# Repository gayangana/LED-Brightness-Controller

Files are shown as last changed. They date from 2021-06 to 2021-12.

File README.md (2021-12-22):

# LED-Brightness-Controller
LED brightness controller with constant current LED drivers

<p align="center">
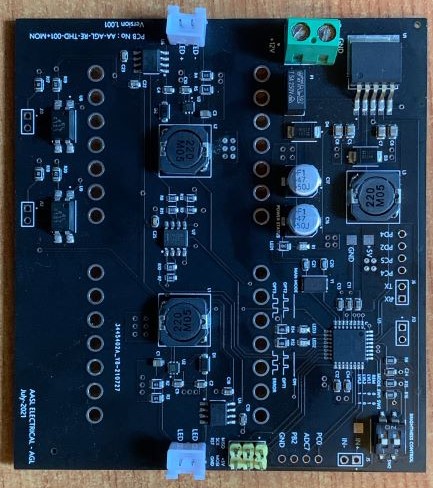
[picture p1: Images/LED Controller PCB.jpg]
  
<p>
  
## Features
- Operates at 12V singal supply
- 2 Ouput channels
- Minimum output voltage - 5V
- Maximum output voltage - 35V
- Maximum output current per channel - 350mA
- LED brightness control with 256 steps (8 bit PWM)
- Overcurrent protection - Maximum input current (5A)
- Current sense capability
- General purpose input/ outputs

## Top Level Block Diagram

<p align="left">
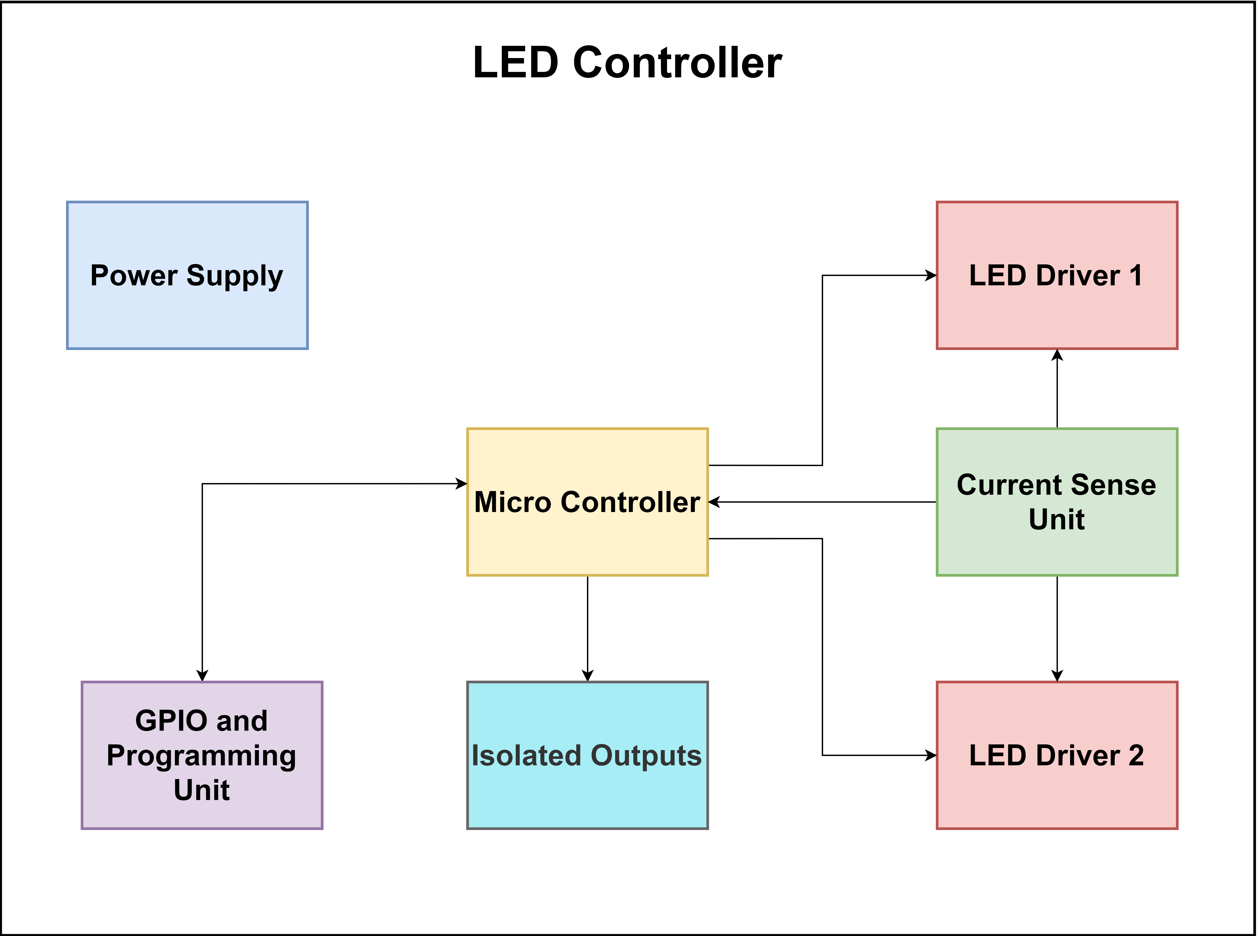
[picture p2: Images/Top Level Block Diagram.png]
  
<p>

## Power Supply Unit - Block Diagram

<p align="left"> 
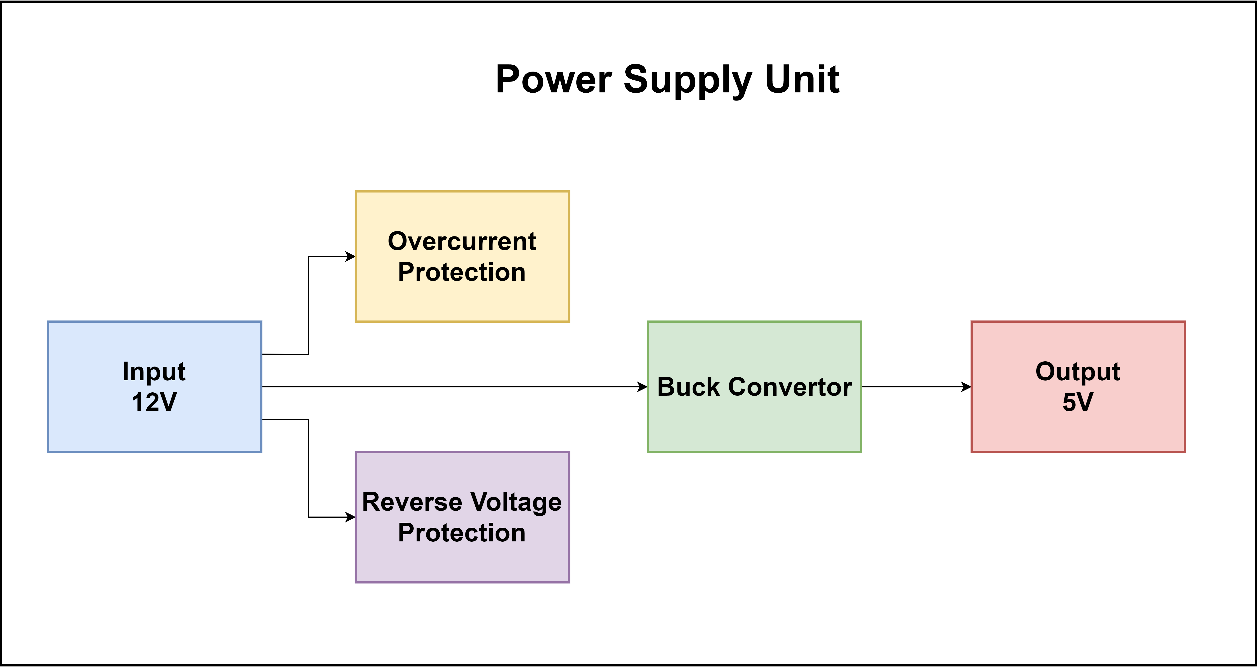
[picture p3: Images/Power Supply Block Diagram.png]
  
<p>

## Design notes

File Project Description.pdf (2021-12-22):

## Primary Objectives

# Design a LED Controller Board

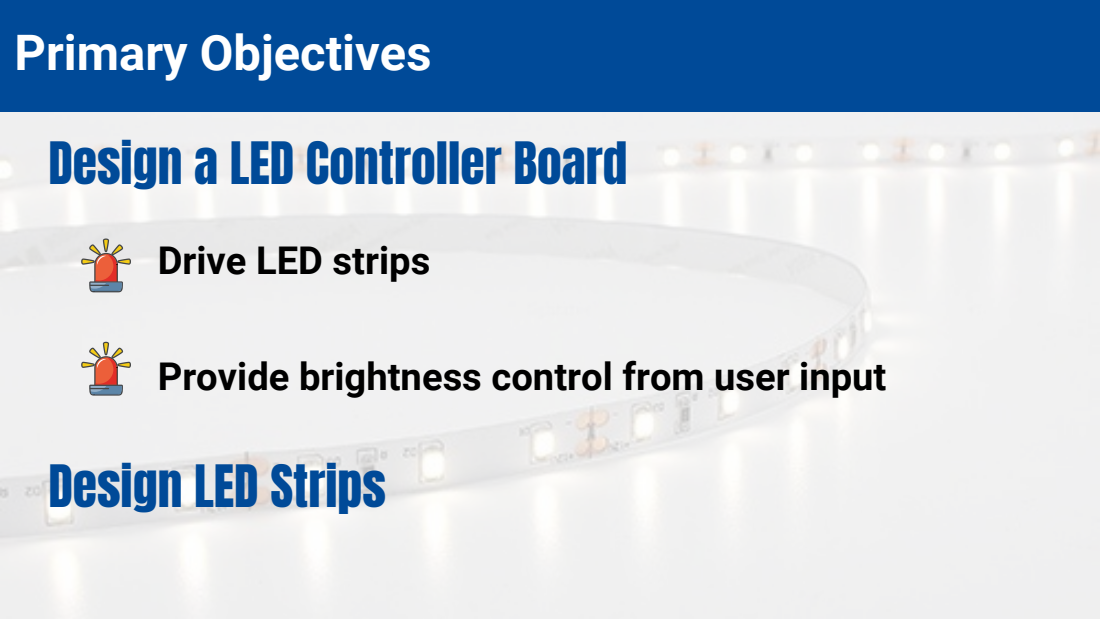
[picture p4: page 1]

Drive LED strips

Provide brightness control from user input
Design LED Strips

## Block Diagram of LED Controller

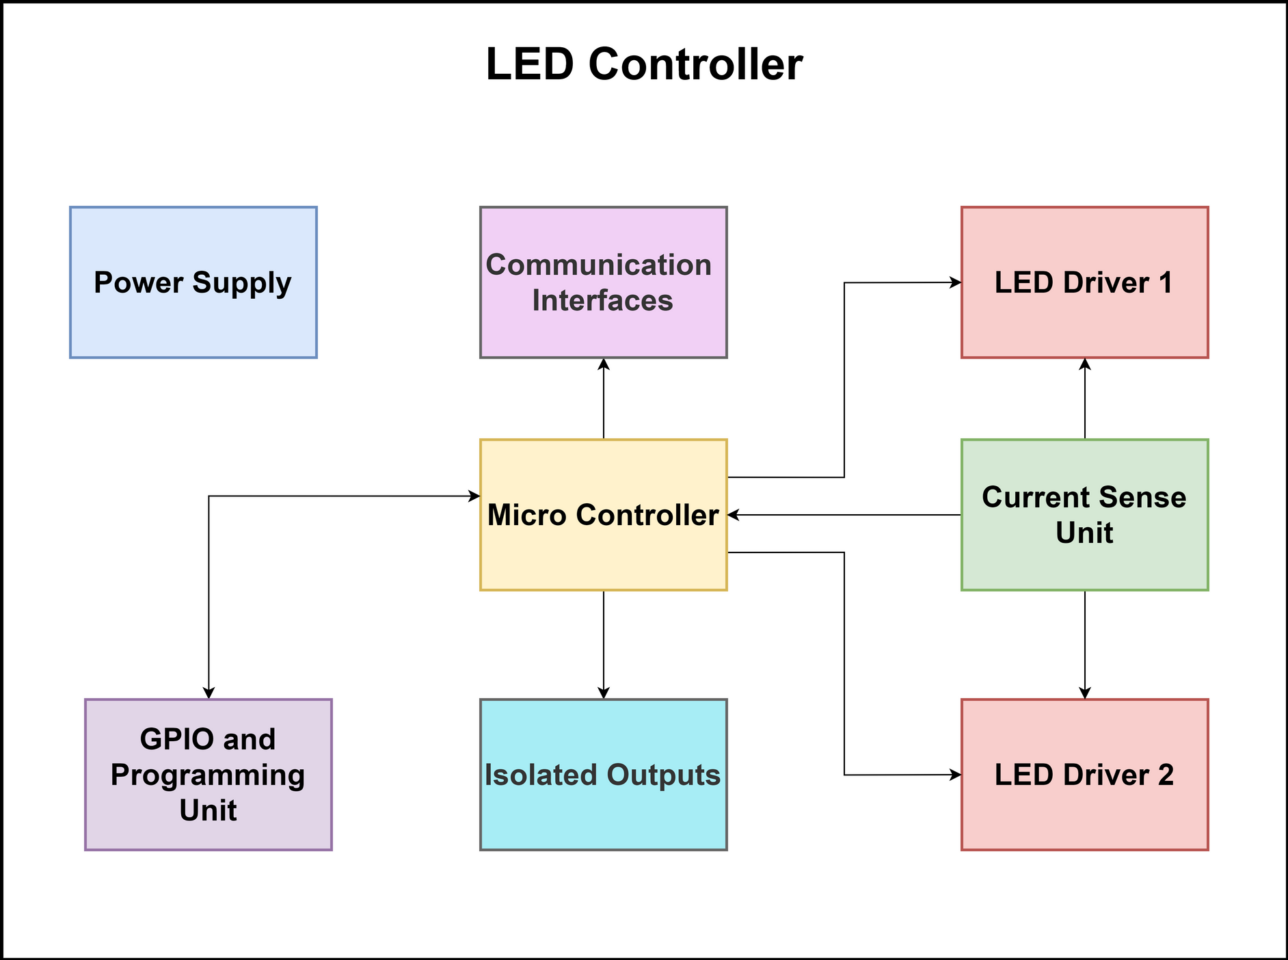
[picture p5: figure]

## Power Supply Unit - Schematic

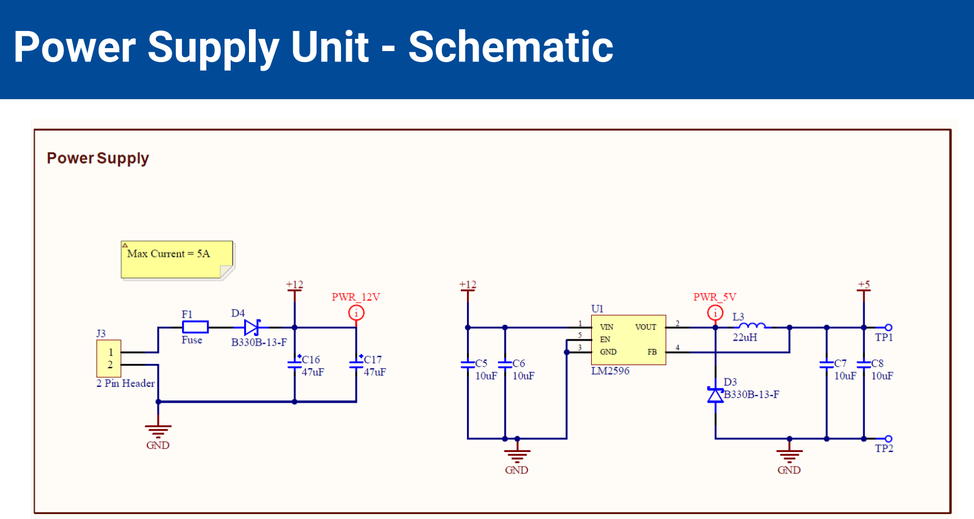
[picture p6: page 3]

## LED Driver

## LED Driver IC : TPS6115

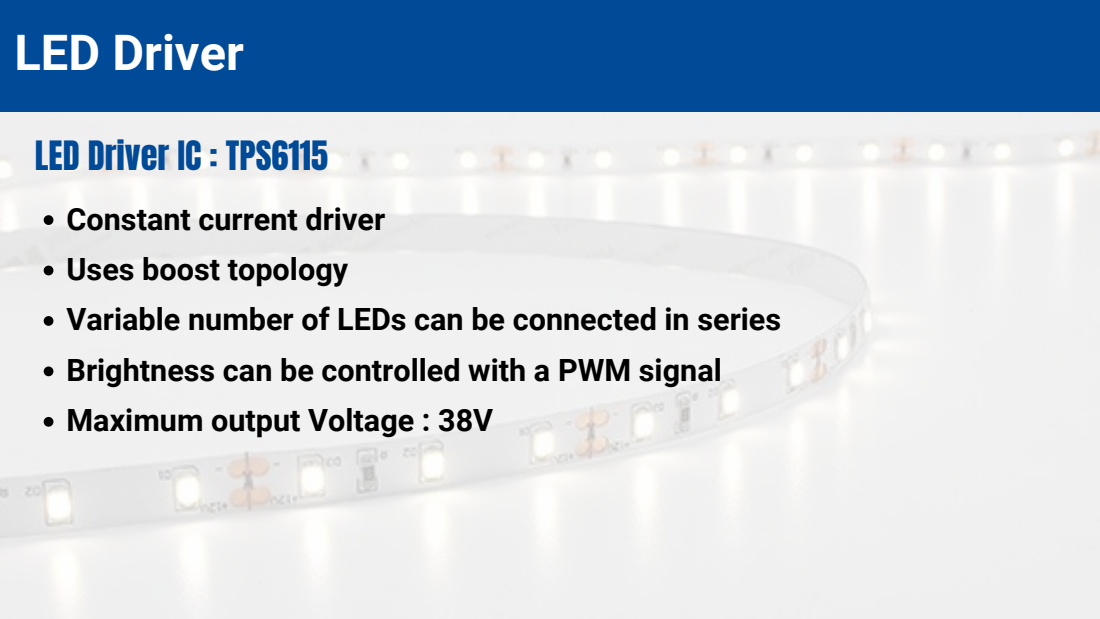
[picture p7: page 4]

Constant current driver
Uses boost topology
Variable number of LEDs can be connected in series
Brightness can be controlled with a PWM signal
Maximum output Voltage : 38V

## LED Driver Unit - Schematic

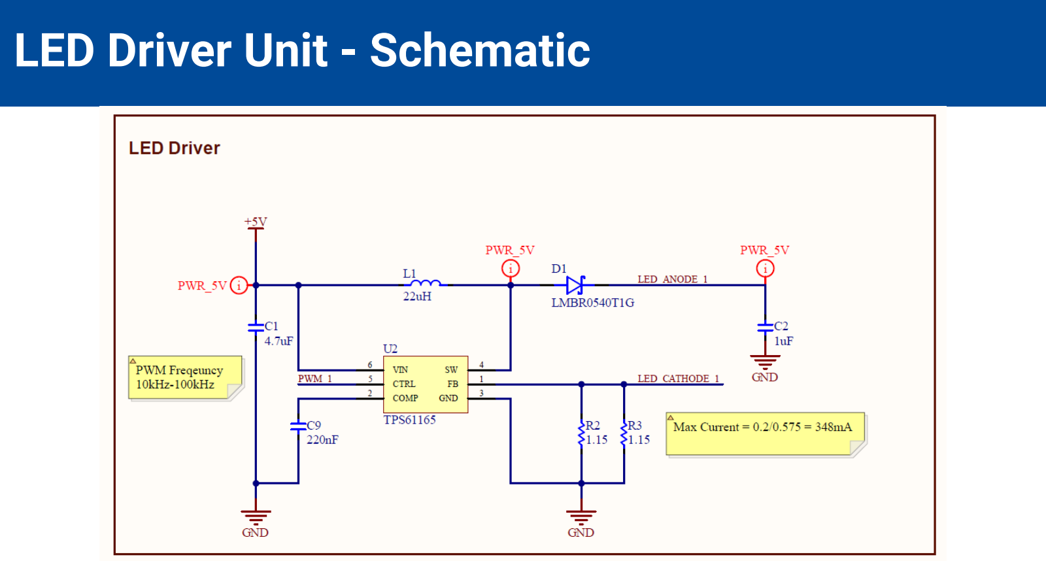
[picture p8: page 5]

## Current Sense Unit

## Current Sense IC : ACS712

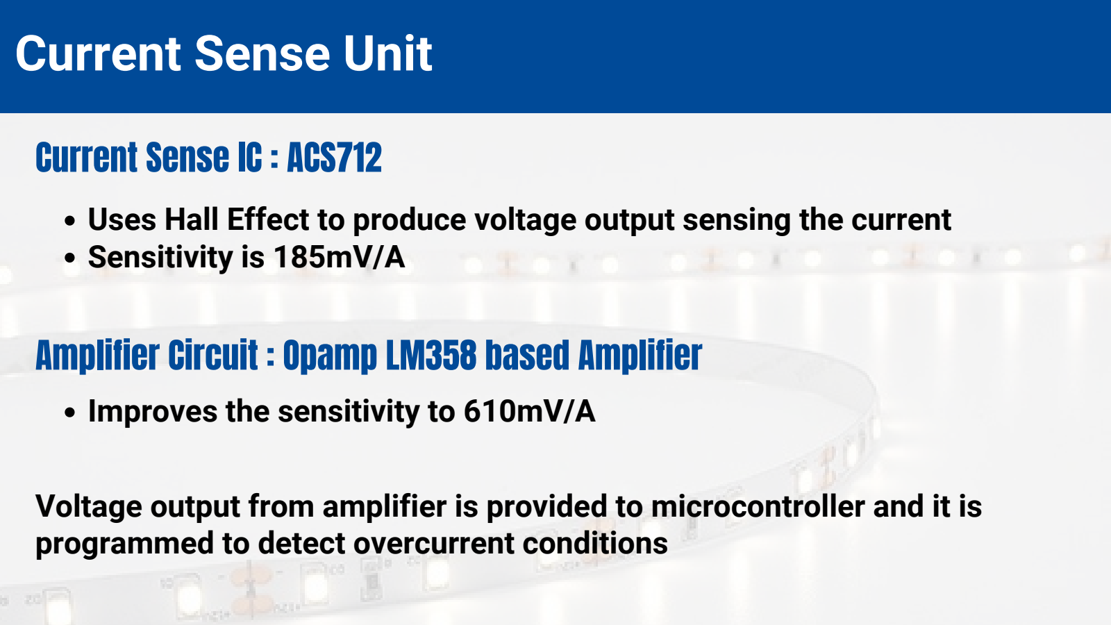
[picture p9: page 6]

Uses Hall Effect to produce voltage output sensing the current Sensitivity is 185mV/A

## Amplifier Circuit : Opamp LM358 based Amplifier

Improves the sensitivity to 610mV/A

Voltage output from amplifier is provided to microcontroller and it is programmed to detect overcurrent conditions

## Current Sense Unit - Schematic

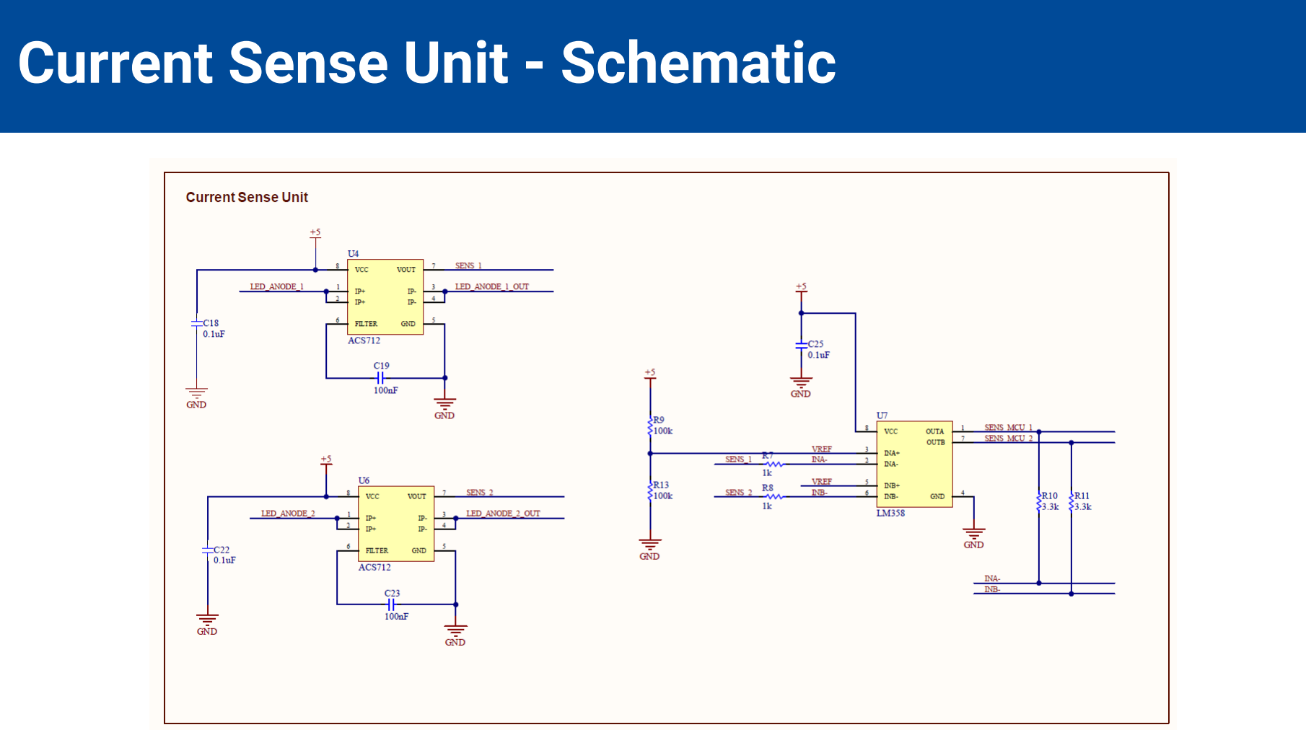
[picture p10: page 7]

## Microcontroller

## Microcontroller : ATmega328P

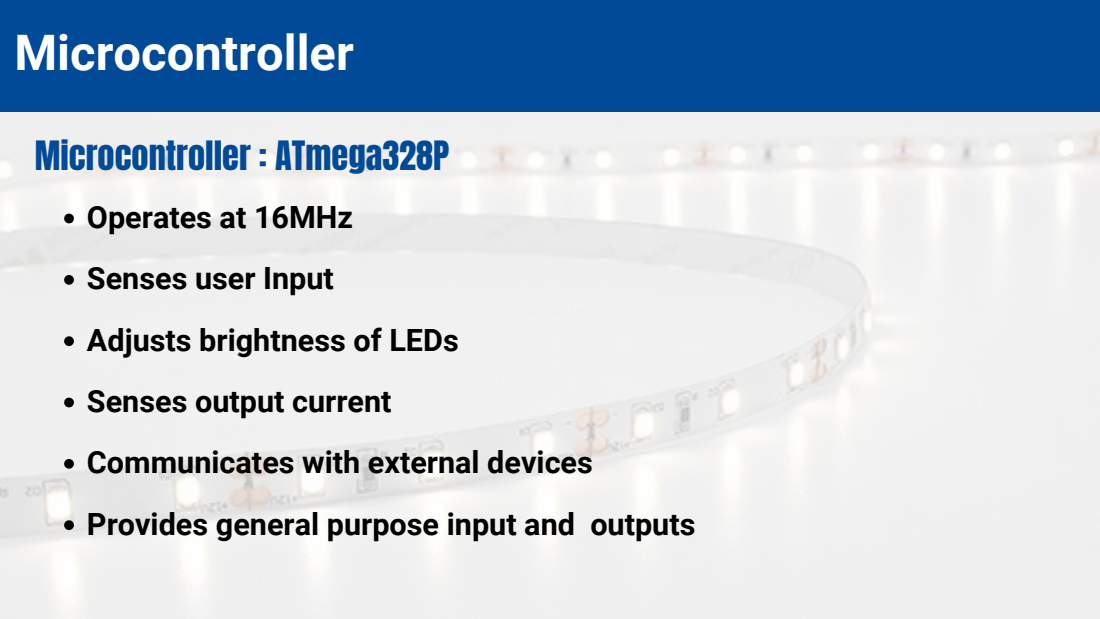
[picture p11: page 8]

Operates at 16MHz
Senses user Input
Adjusts brightness of LEDs
Senses output current
Communicates with external devices
Provides general purpose input and outputs

## Microcontroller - Schematic

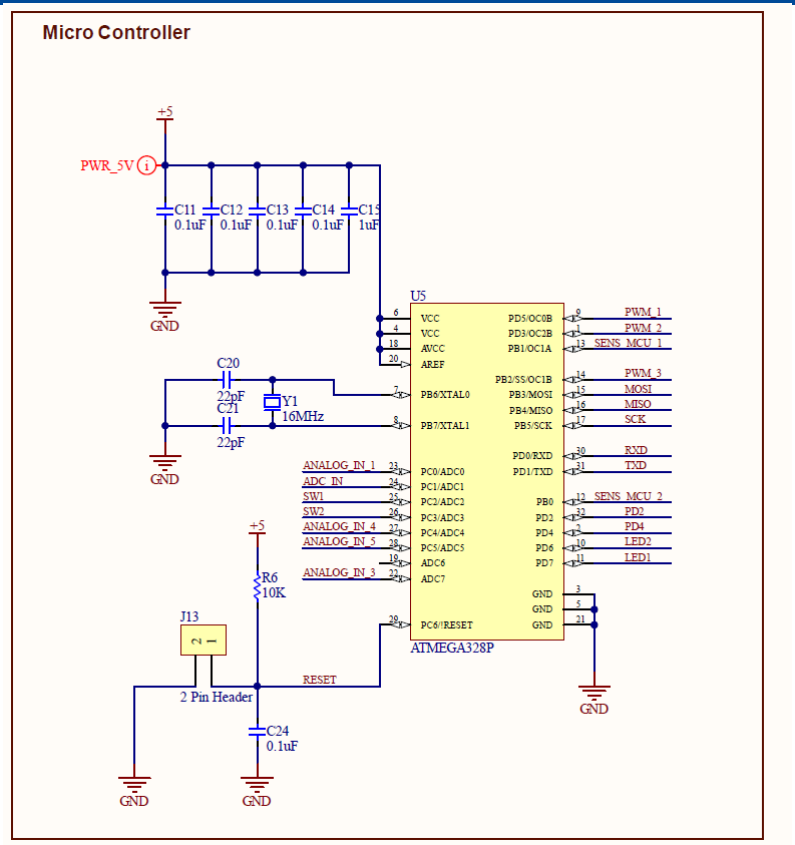
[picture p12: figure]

## PCB Design

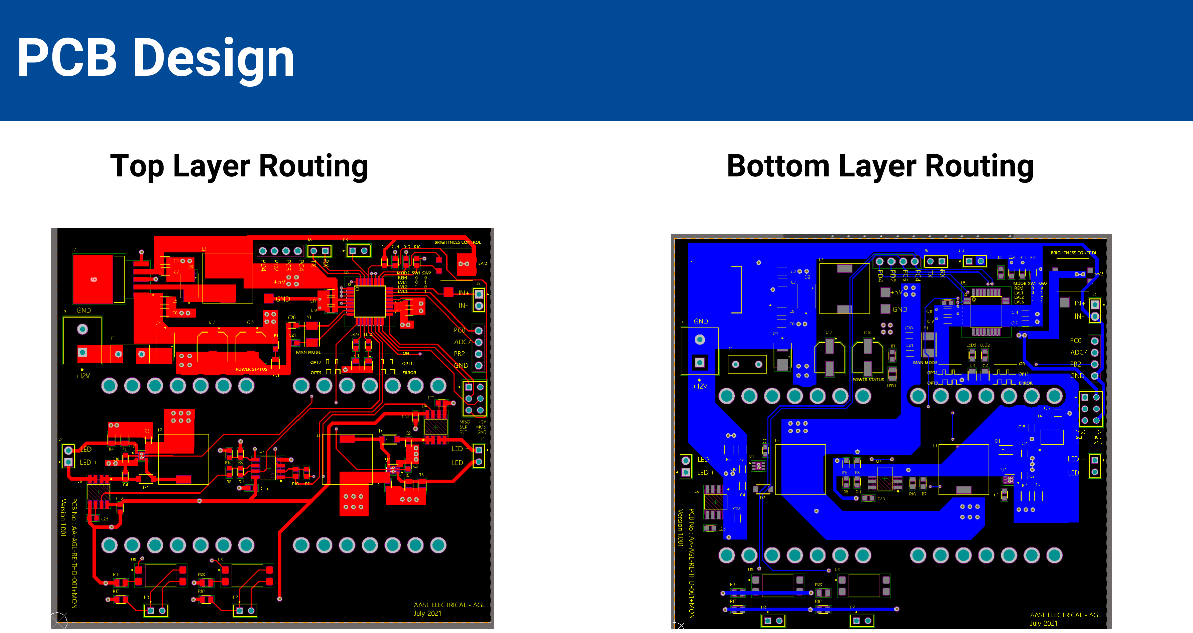
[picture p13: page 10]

Top Layer Routing | Bottom Layer Routing

## Assembled PCB

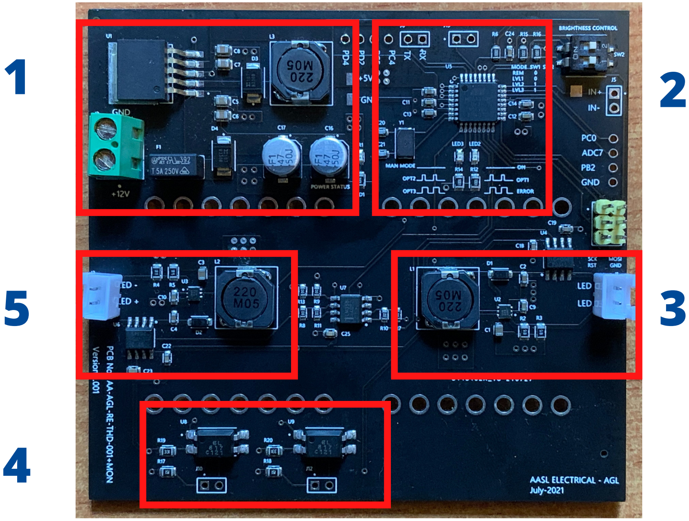
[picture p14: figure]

1- Power Supply
2 - Microcontroller Unit
3 - LED Driver 2 and current sense unit 4 - Isolated Outputs
5 - LED Driver 1 and current sense unit

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
1 - GPIO 2 - UART 3 - Reset 4 - Manual Control 5 - GPIO 6 - SPI/ Programming 7 - LED output 2 8 - Isolated Outputs 9 - LED Output 1

10 - Power Input

67

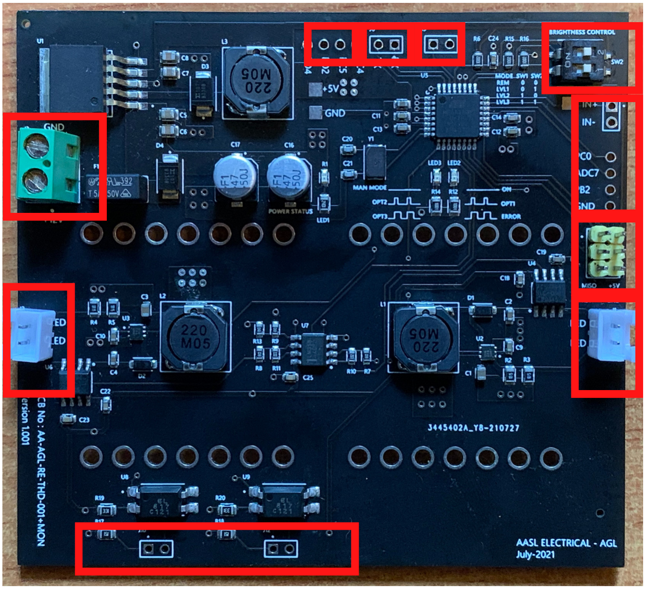
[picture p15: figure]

8

9

10

## LED Strip - Schematic

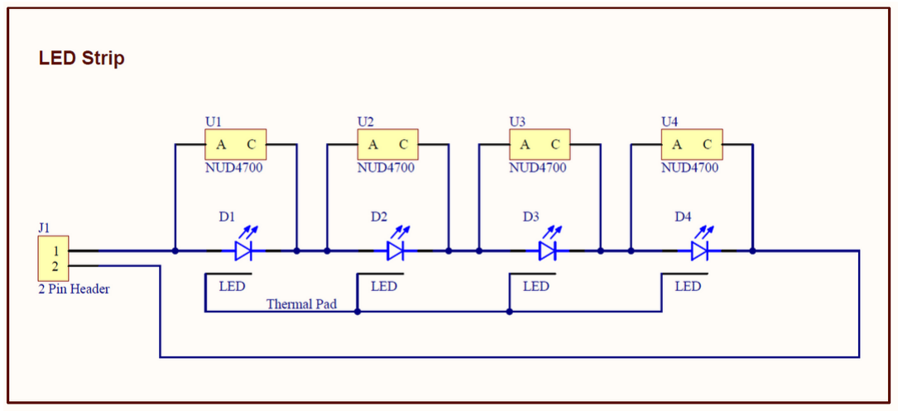
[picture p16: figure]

LEDs are connected in series

Maximum power dissipation of a LED is 1W

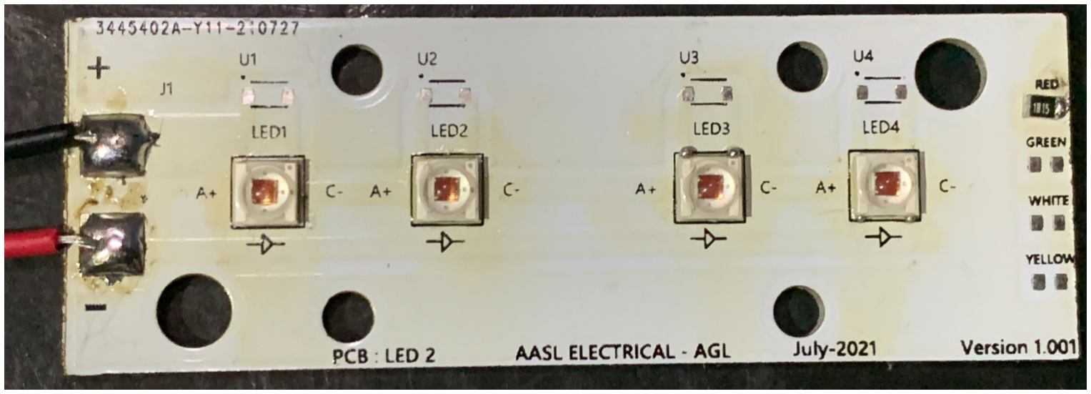
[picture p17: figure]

NUD4700 is a LED Shut and it provides a short ciruit path between LED anode and cathode, if a LED is mal-functioning

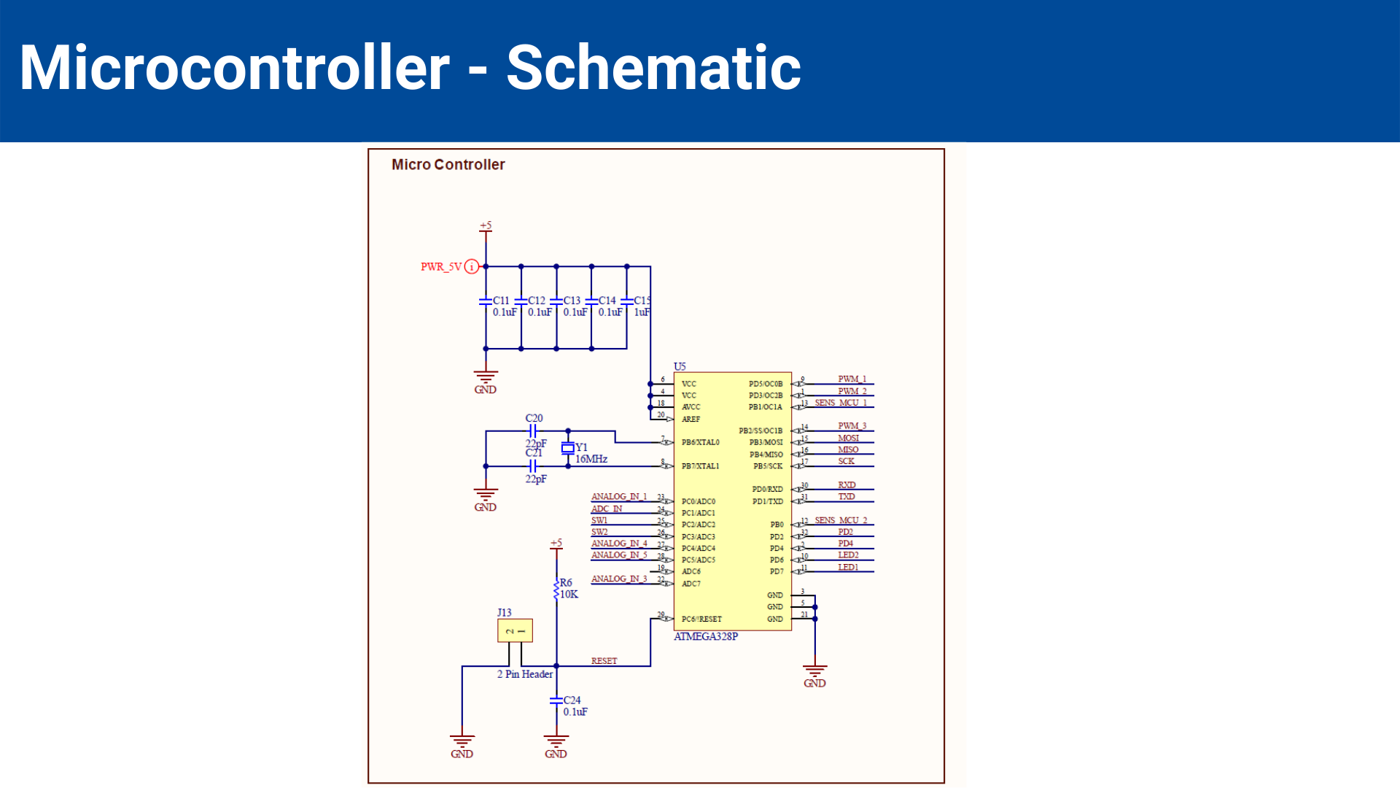
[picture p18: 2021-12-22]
Images/Microcontroller.png

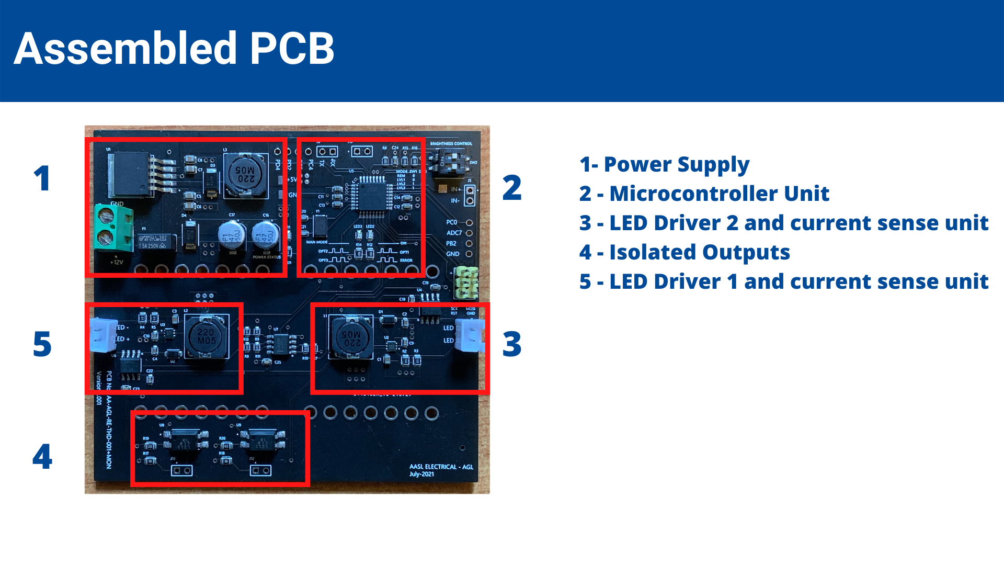
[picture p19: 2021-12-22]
Images/Sub Sections.png

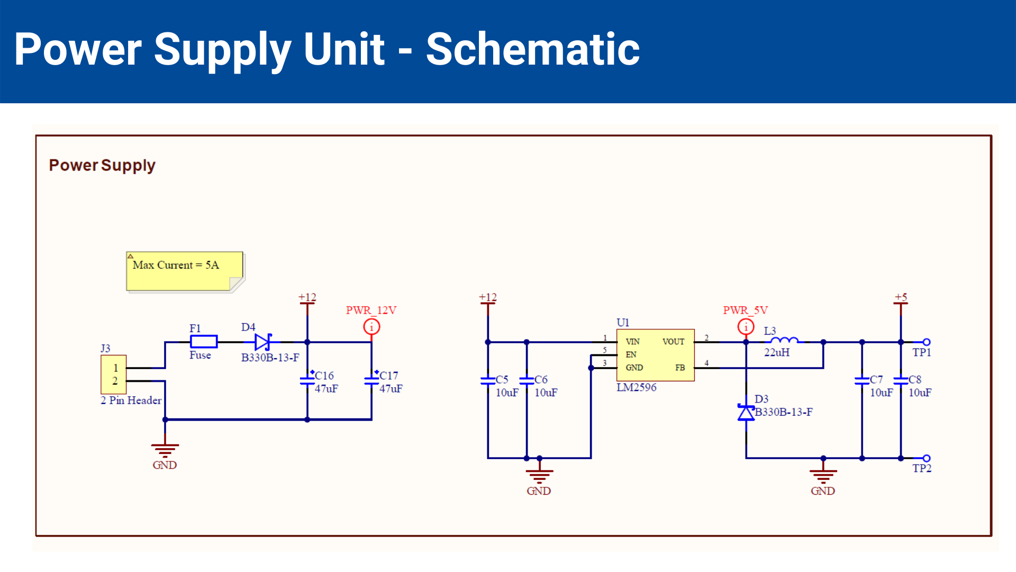
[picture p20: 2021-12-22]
Images/Power Supply Unit.png

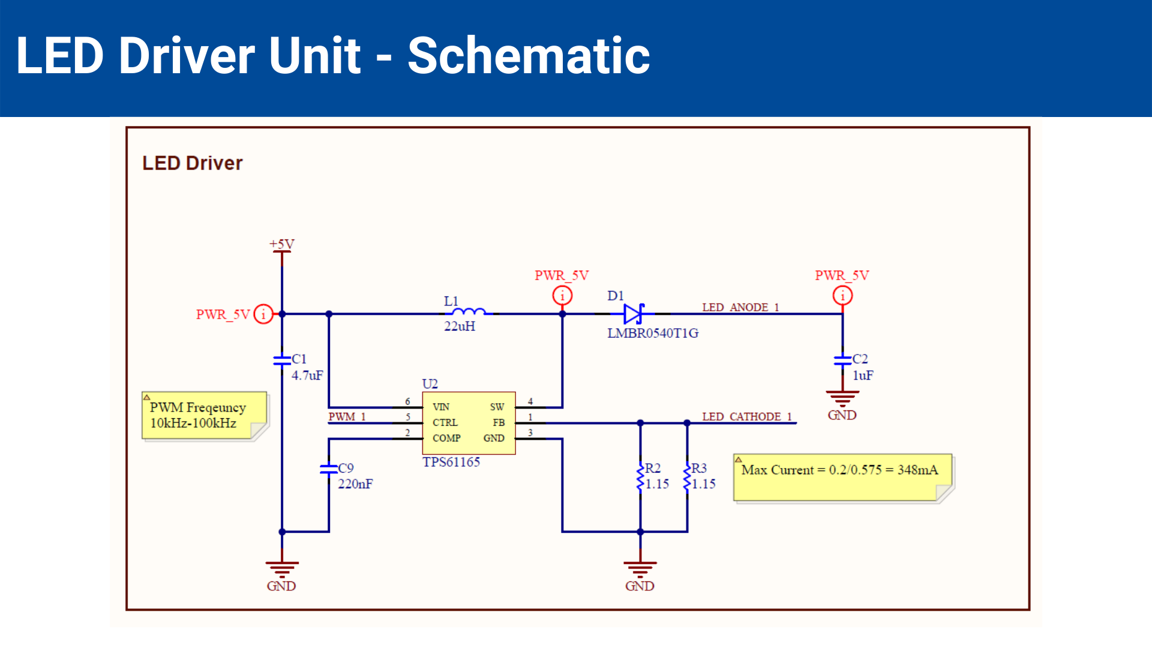
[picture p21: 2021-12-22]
Images/LED Driver Unit.png

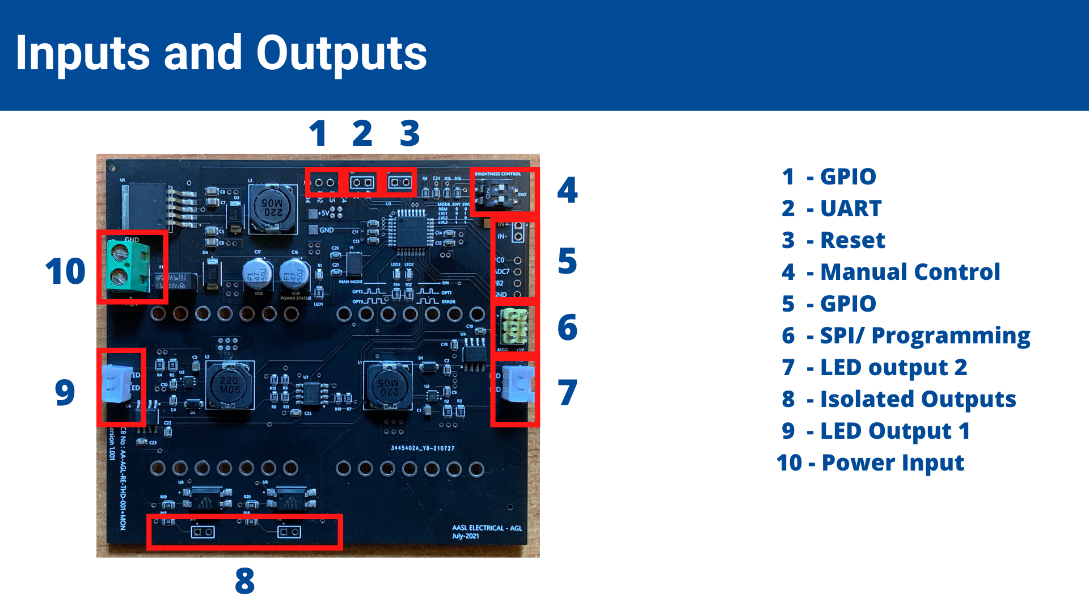
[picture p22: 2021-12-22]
Images/Inputs and Outputs.png

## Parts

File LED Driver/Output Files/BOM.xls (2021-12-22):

Comment | Designator | Package | LCSC Part
0603WAF1003T5E | R9,R13 | RES603 | C25803
LM358DR2G | U7 | SOIC127P600X175-8N | C7950
0805W8J0331T5E | R19,R20 | RES805 | C25306
TZ-P2-0603YGTCS1-0.6T | LED1,LED2,LED3 | LED603 | C72038
B330B-13-F | D3,D4 | B330B-13-F | C134450
0805W8F1002T5E | R6,R15,R16 | RES603 | C17414
0603WAF3301T5E | R10,R11 | RES603 | C22978
ATMEGA328P-AU | U5 | ATMEGA328P-AU | C14877
0805W8F115KT5E | R2,R3,R4,R5 | RES805 | C17373
39215000000 | F1 | 39215000000 | C142694
CL10A105KB8NNNC | C2,C4,C15 | RES603 | C15849
0805W8F2401T5E | R1 | RES805 | C17526
0805W8J0151T5E | R17,R18 | RES805 | C25283
CL21A475KBQNNNE | C1,C3 | RES603 | C98192
CL10C220JB8NNNC | C20,C21 | RES603 | C1653
CDRH104RNP-220NC | L1,L2,L3 | CDRH104RNP-220NC | C87002
TPS61165DRVR | U2,U3 | TPS611DRVR | C122568
ACS712ELCTR-05B-T | U4,U6 | SOIC127P600X175-8N | C44471
CC0603KRX7R9BB104 | C19,C23 | RES603 | C14663
HMK107B7104KAHT | C11,C12,C13,C14,C18,C22,C24,C25 | RES603 | C14663
GRM188R61E106KA73D | C5,C6,C7,C8 | RES603 | C15850
LMBR0540T1G | D1,D2 | LMBR0540T1G | C78545
X503216MSB2GI | Y1 | X503216MSB2GI | C112572
LM2596S-5.0/TR | U1 | LM2596-TO263 | C194349
EM-02KP | SW2 | EM-02KP | C129078
0603WAF1001T5E | R7,R8 | RES603 | C21190
VEJ470M1HTR-0607 | C16,C17 | VEJ470M1HTR-0607 | C134775
CL10B224KB8NNNC | C9,C10 | RES603 | C64705
EL817S1(C)(TU)-F | U8,U9 | EL817S1 | C106900
0805W8F1001T5E | R12,R14 | RES805 | C17513

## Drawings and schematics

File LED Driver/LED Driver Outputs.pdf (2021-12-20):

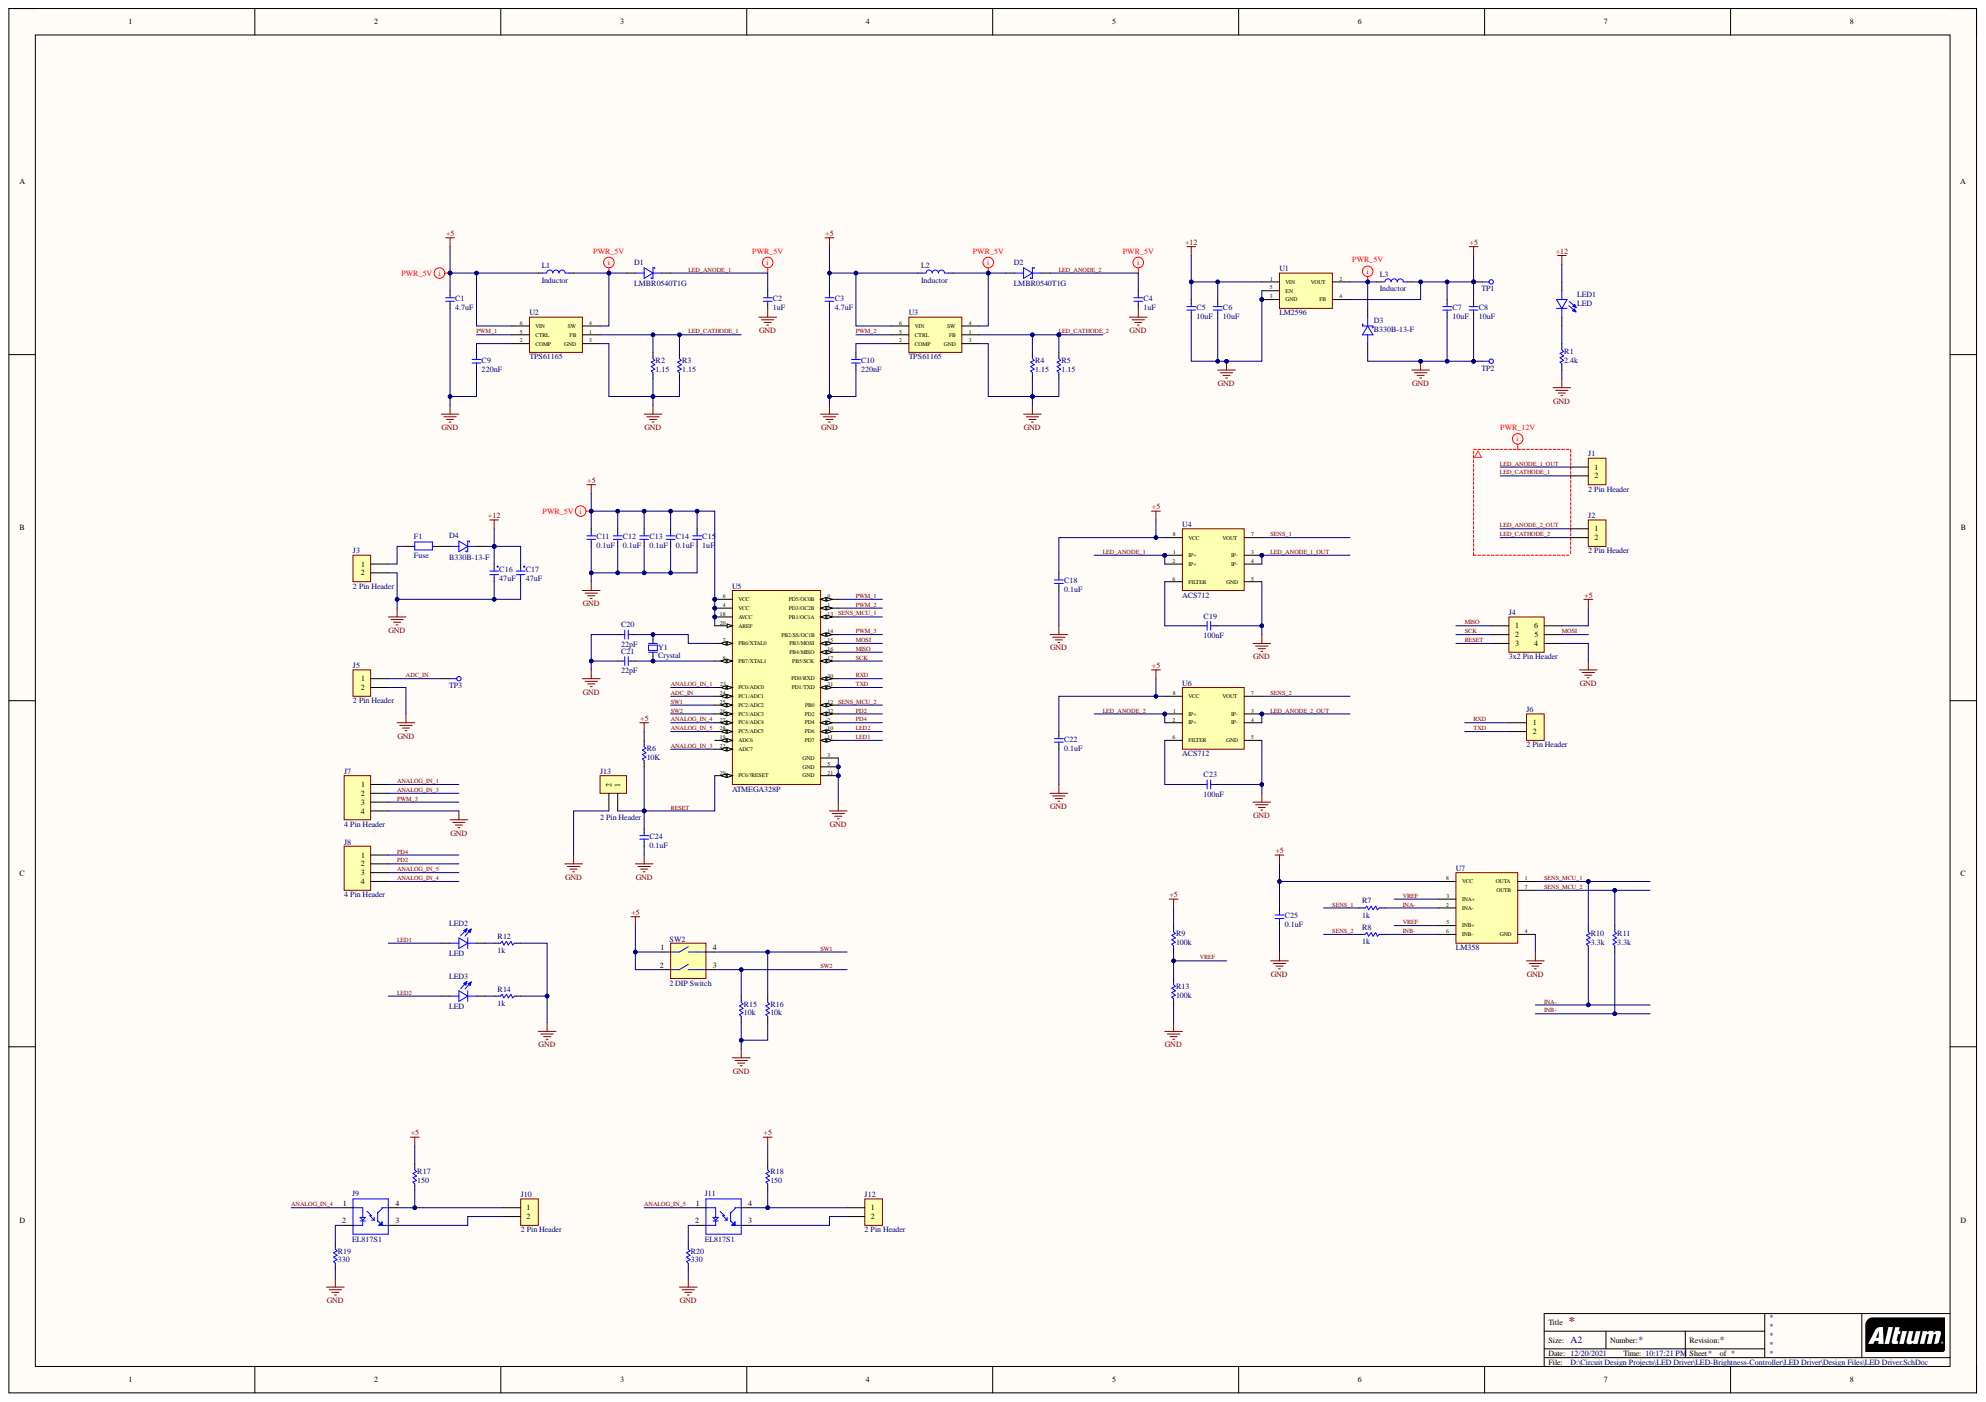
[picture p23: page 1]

D:\Circuit Design Projects\LED Driver\LED-Brightness-Controller\LED Driver\Design Files\LED Driver.SchDoc

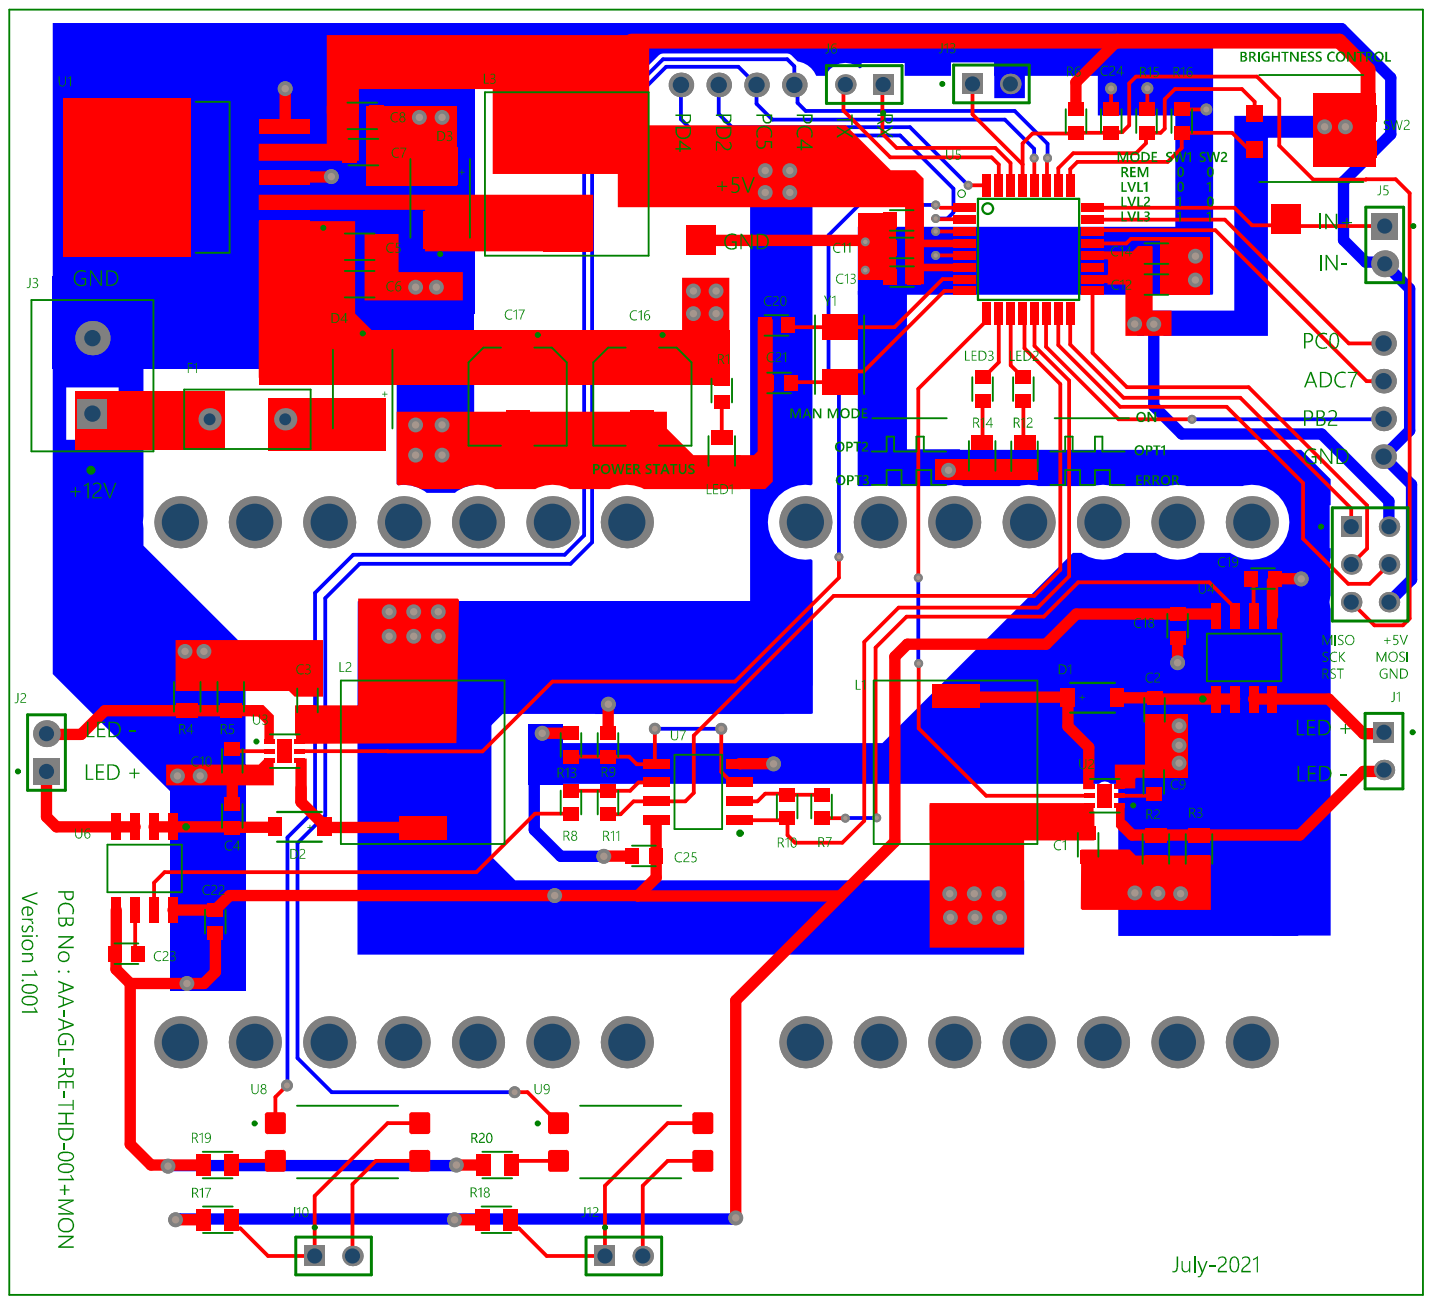
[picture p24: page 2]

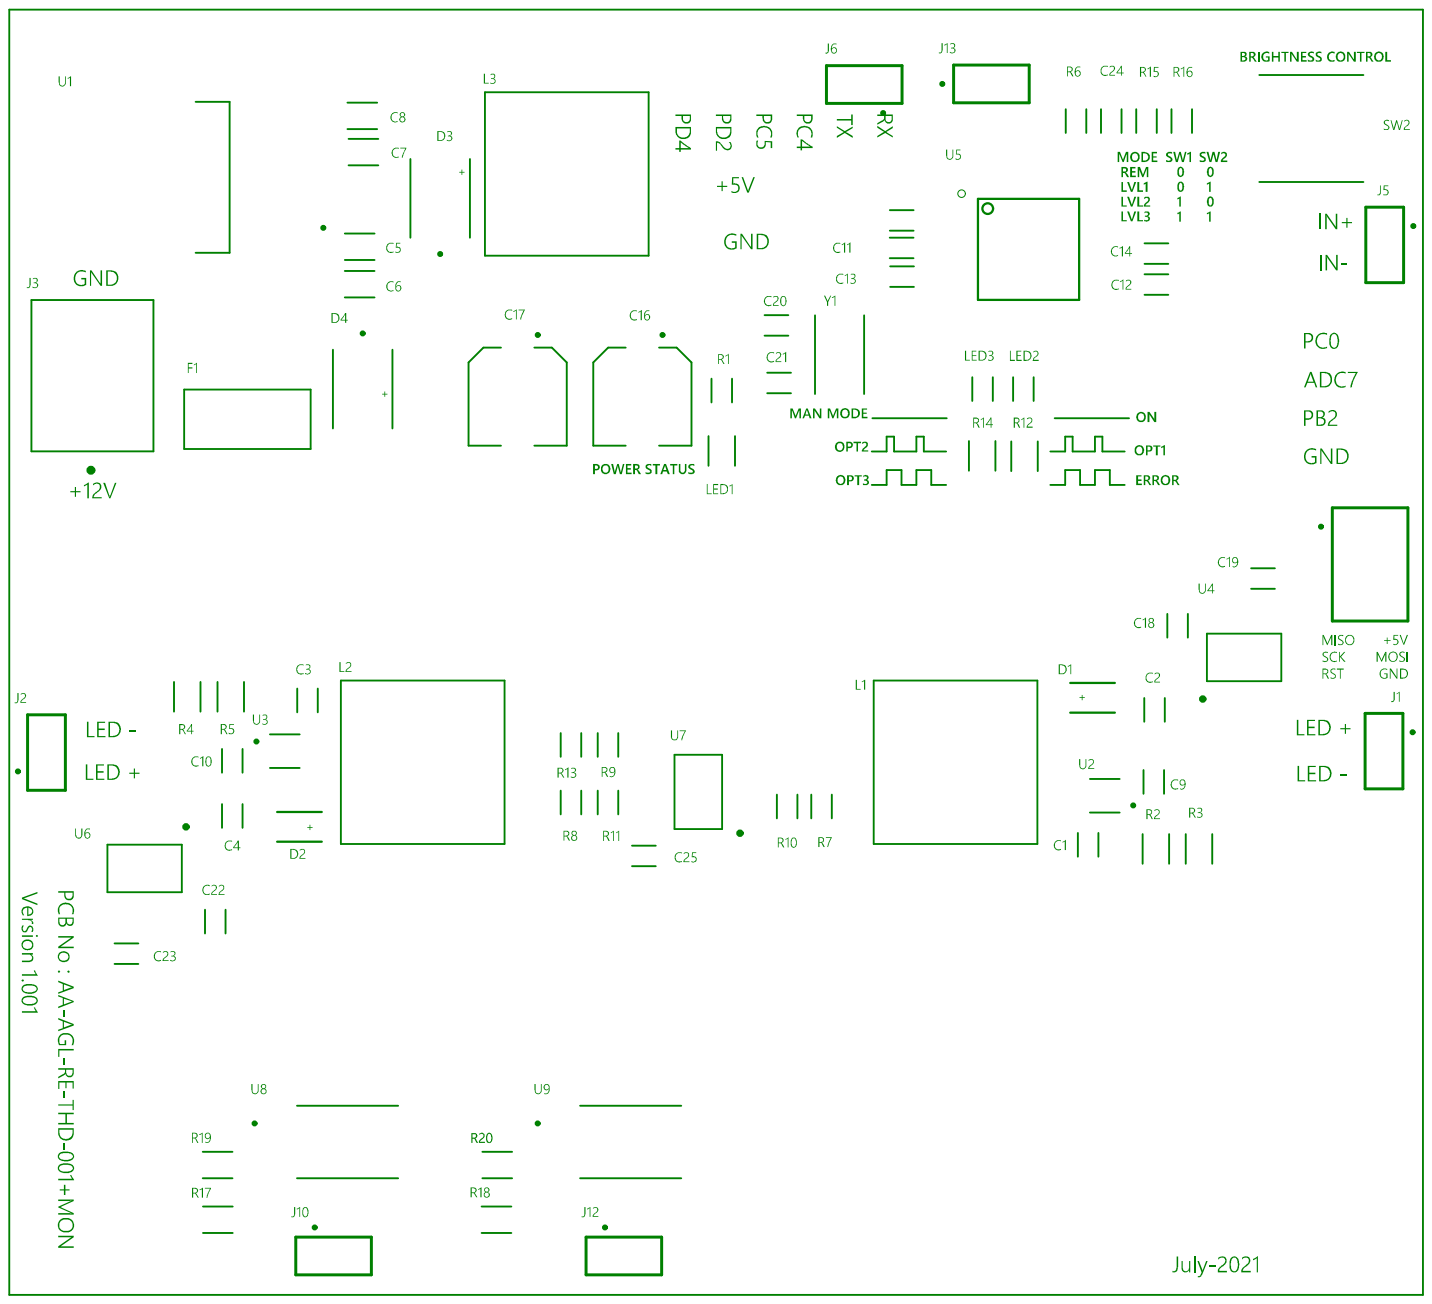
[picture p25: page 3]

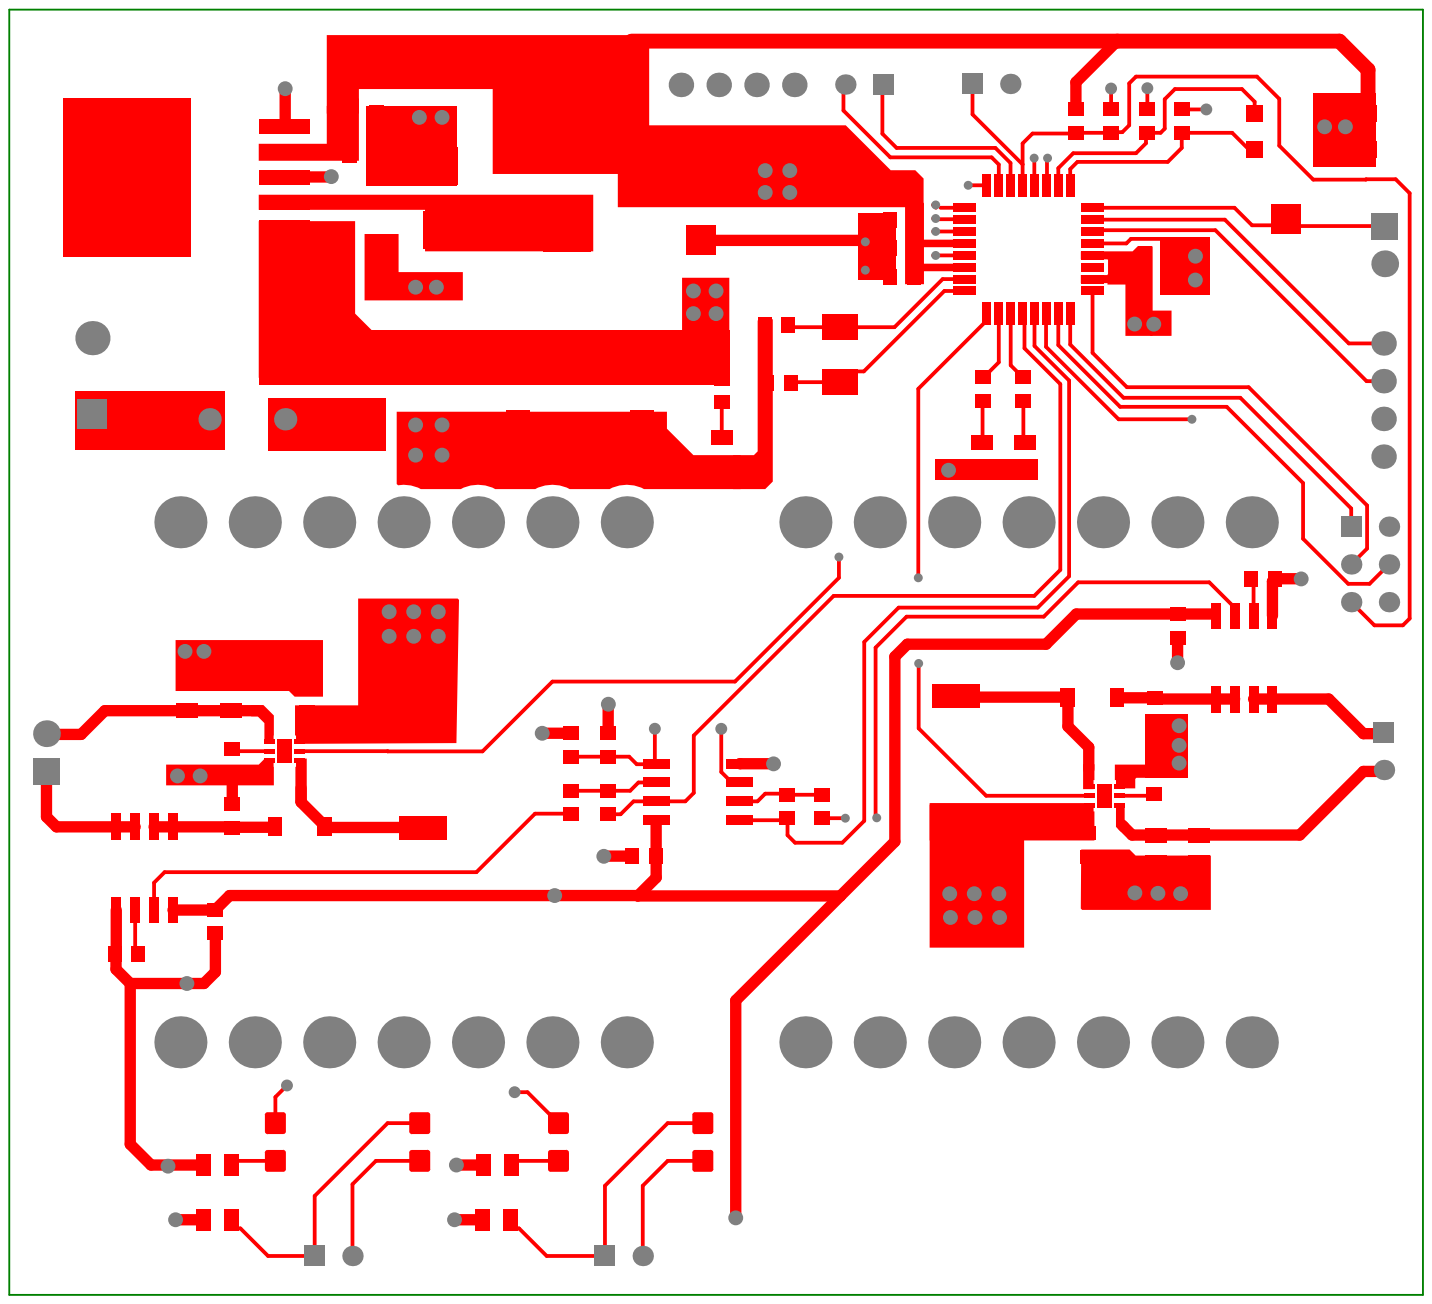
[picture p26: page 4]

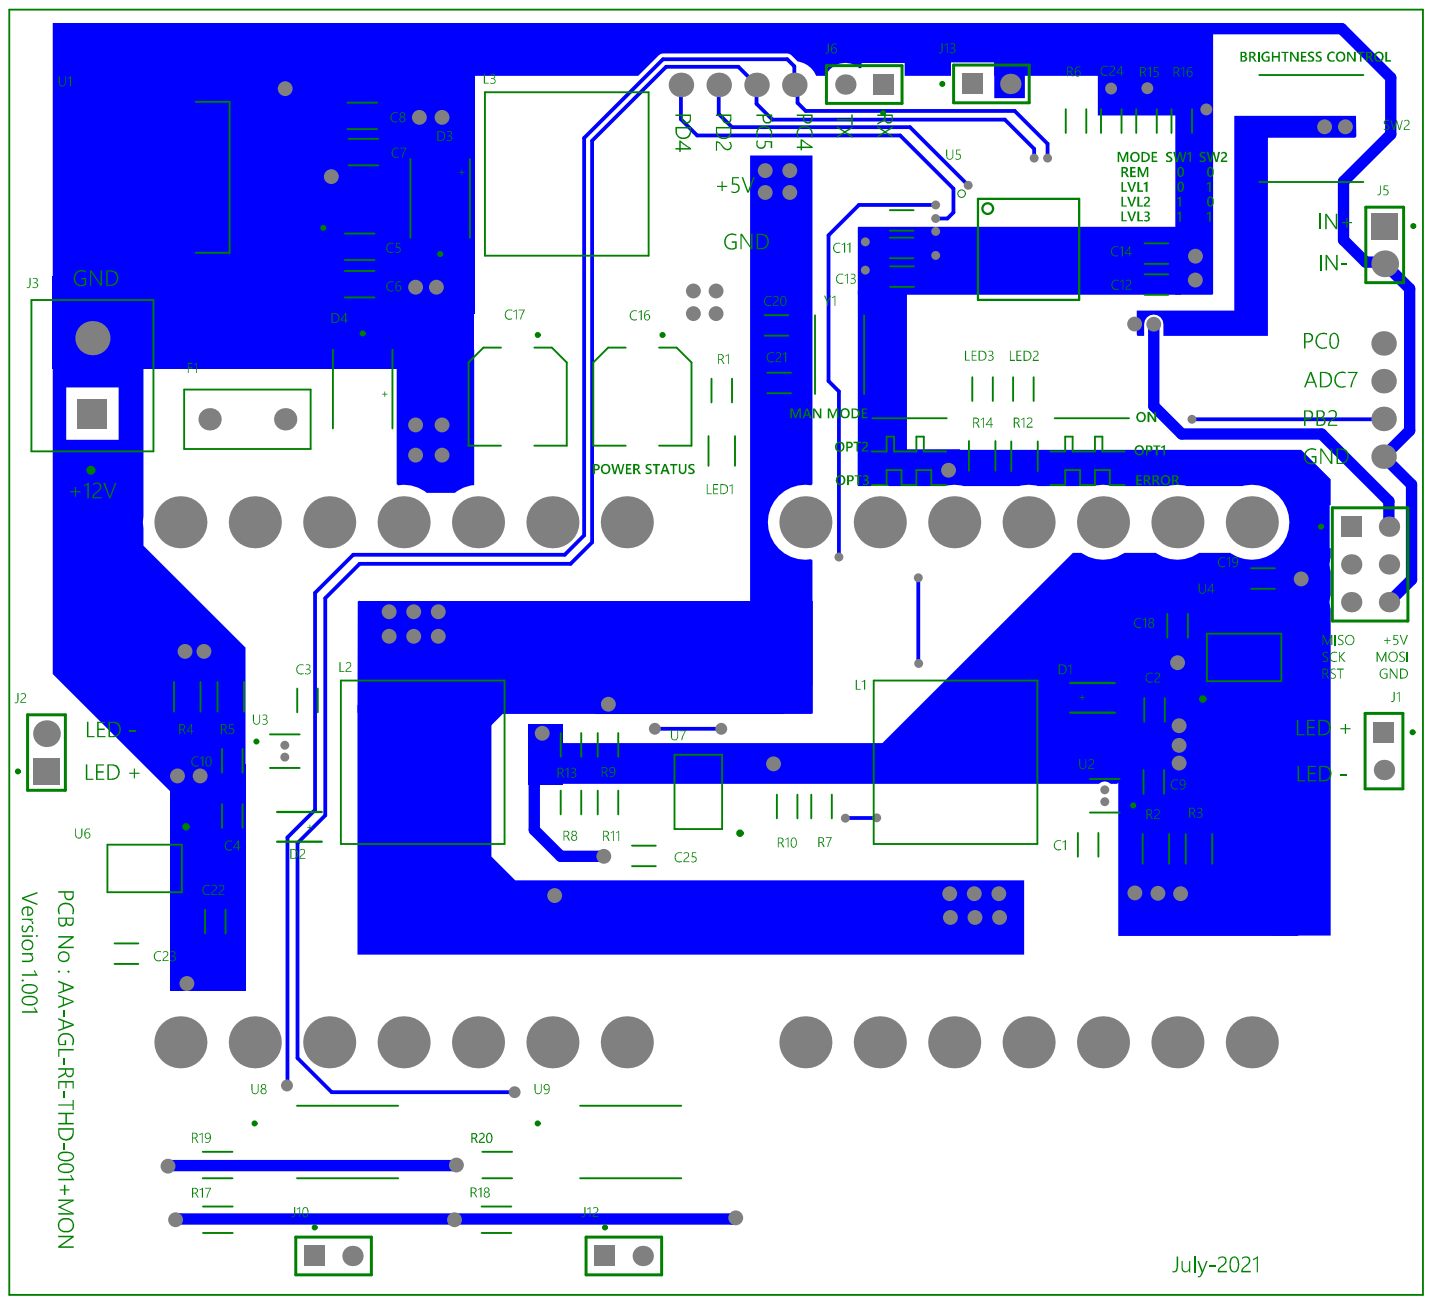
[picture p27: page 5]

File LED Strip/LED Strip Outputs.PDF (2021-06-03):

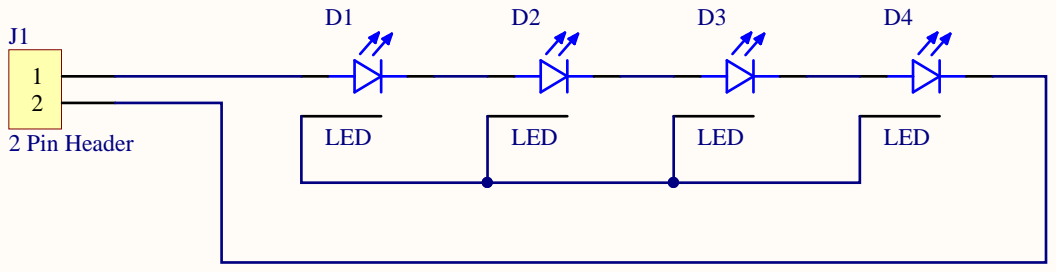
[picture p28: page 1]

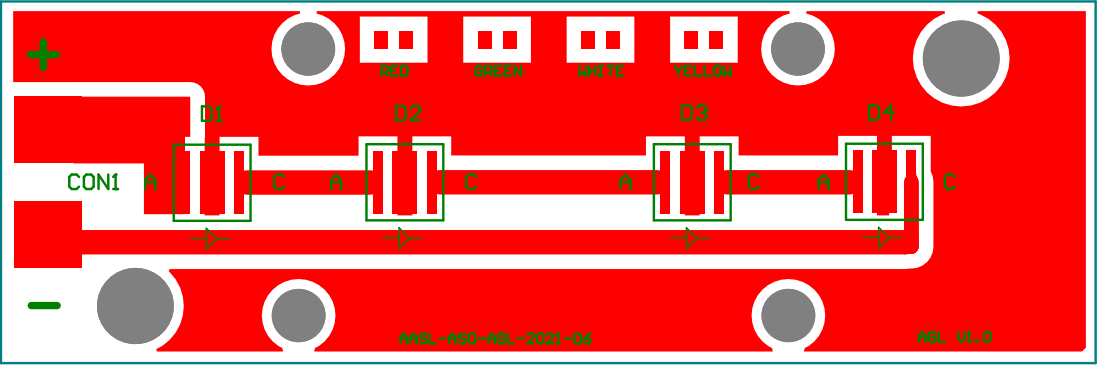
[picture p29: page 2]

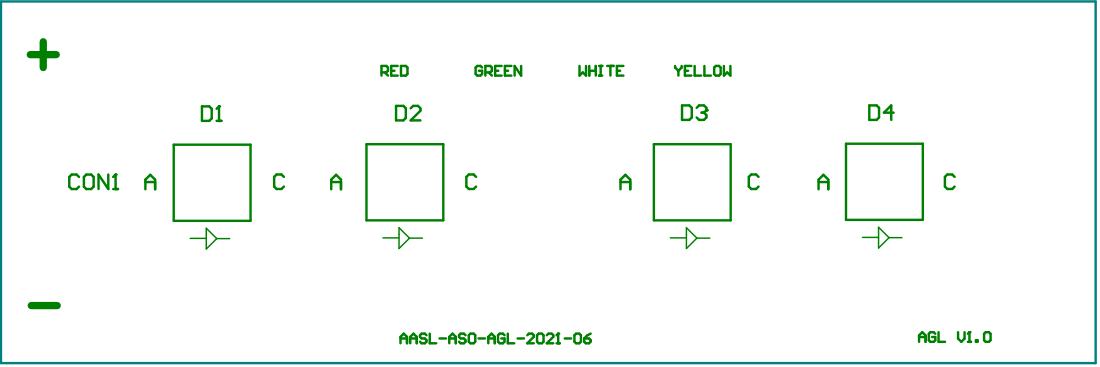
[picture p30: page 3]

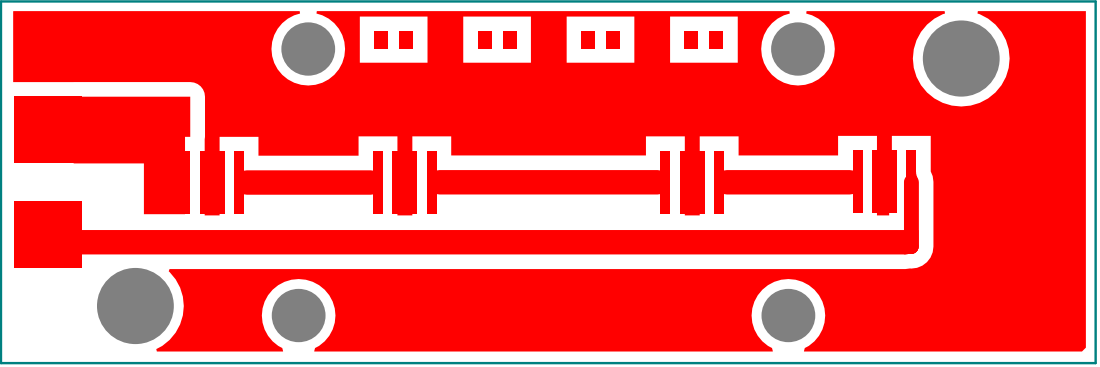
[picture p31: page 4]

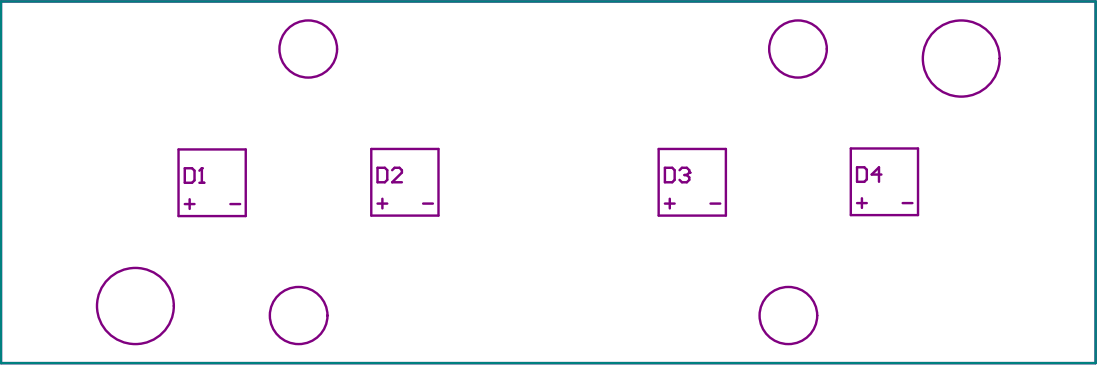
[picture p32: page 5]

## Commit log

2021-07-08 Add LED Driver schematic and components
    [LED Driver.PrjPcb, LED Driver.SchDoc, PcbLib.PcbLib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]
2021-07-09 Add PCB and place components
    [LED Driver PCB.PcbDoc, LED Driver.PrjPcb, LED Driver.SchDoc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]
2021-07-17 Route connections
    [PcbLib.PcbLib, Schlib.SchLib]
2021-07-18 Add optocoupler
    [LED Driver PCB.PcbDoc, LED Driver.SchDoc, PcbLib.PcbLib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]
2021-12-20 Add project outputs
    [LED Driver PCB.PcbDoc, LED Driver bom.xlsx, LED Driver.PrjPcb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]
2021-12-22 Add BOM and CPL files
    [BOM.xls, LED Driver.PrjPcb, Pick and Place.csv]
2021-12-22 Modify BOM
    [LED Driver bom.xlsx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]
